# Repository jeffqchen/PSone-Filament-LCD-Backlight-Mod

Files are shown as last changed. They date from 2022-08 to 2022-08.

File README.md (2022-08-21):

# PSone Filament LCD Backlight Mod

The official PSone LCD screen has a fragile backlight system. The inverter and the CCFL tube could kick the bucket on itself. Sometimes you can't even figure out what went wrong with the backlight system. It's also nearly impossible to find the exact replacement parts at a reasonable price, even if you managed to figure it out.

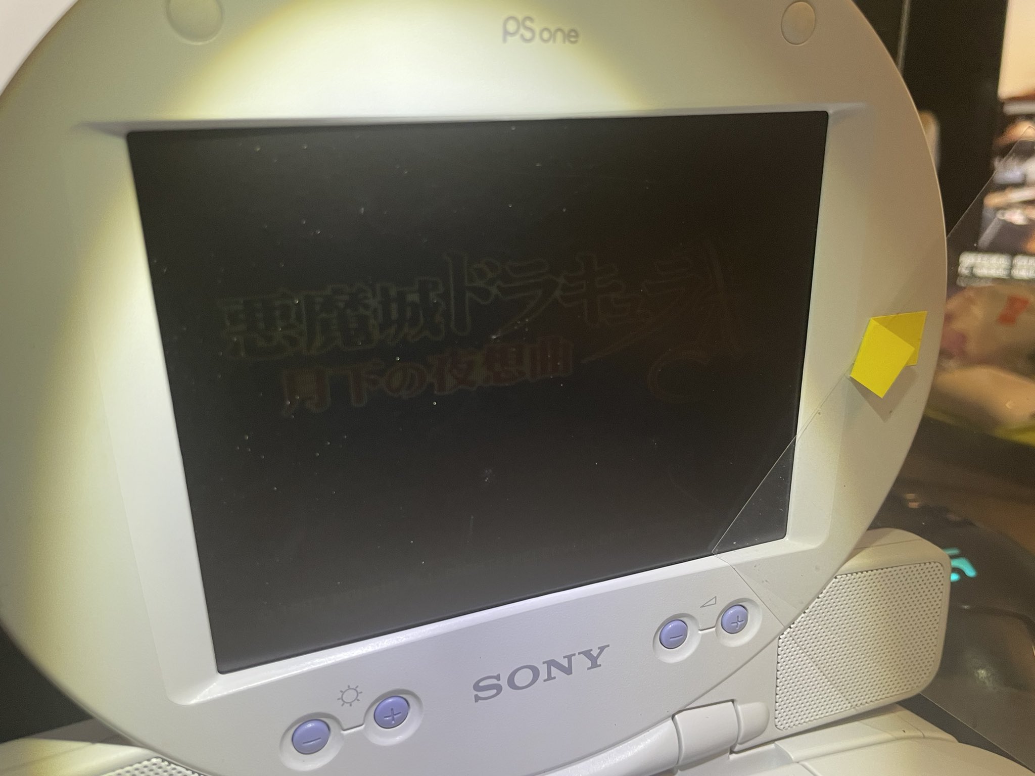
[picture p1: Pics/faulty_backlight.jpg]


Previously, there were multiple attempts of similar mods. But they all used singular LEDs, and resulted in uneven backlight that's difficult to look at. This new type of flexible filament LED provides the uniformity as good as the CCFL tube, and is very easy to manipulate. More importantly, they are very affordable.

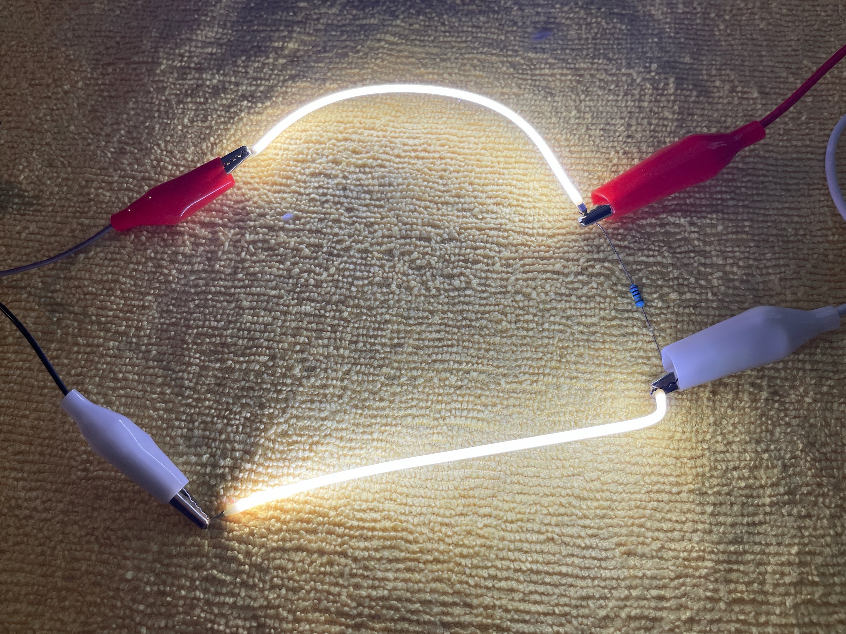
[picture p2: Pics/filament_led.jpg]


So here is my solution, just in case you are facing the dilemma (however, by all means, please try to diagnose and fix the original system if possible).

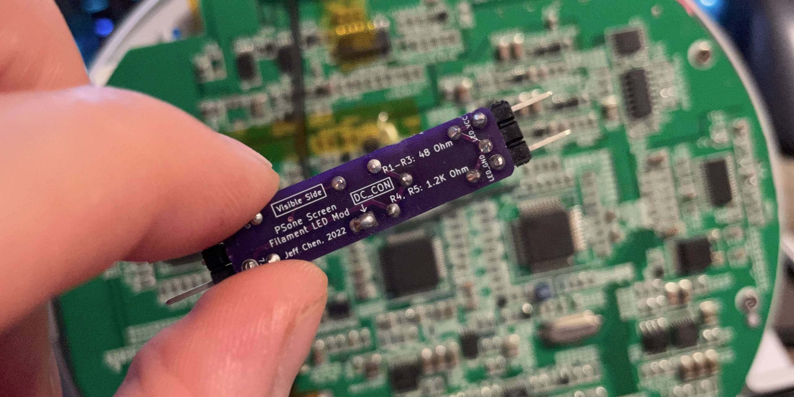
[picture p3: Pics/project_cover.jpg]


This design takes the 7.5V from the power input, runs it through an NPN amplifier, to feed power through two 3V flexible filament LED strips and some current-limiting resistors, controlled by the 5V_CON signal from the console.

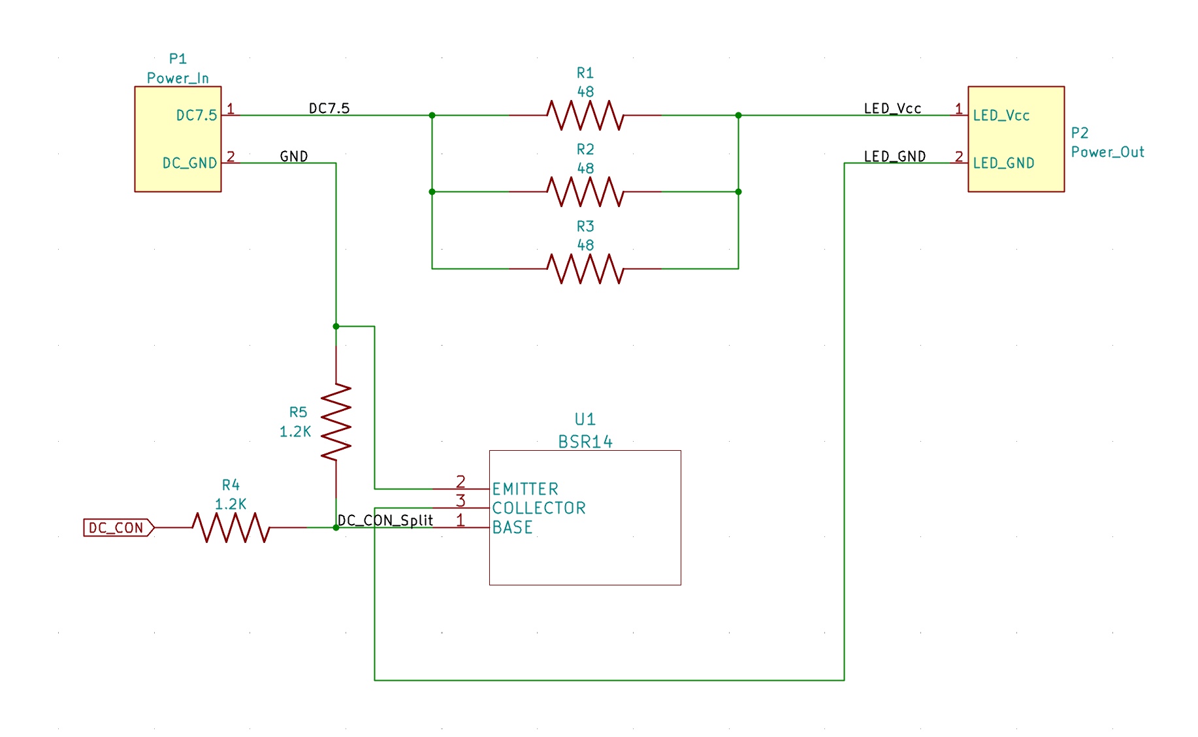
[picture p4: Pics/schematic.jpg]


Please note these values were fine tuned and do not match the perfect calculations. Somehow these filament LED strips do not drop the claimed voltage and I had to reduce the value of the current-limiting resistors to make them emit enough light. I did let the system run for an extended period of time to make sure it would last. The operation temperature was still much lower than the original design.

----------
## Parts

- [PCB](https://oshpark.com/shared_projects/M3fZRLg5)

- BSR14 NPN Amplifier / SOT23-3 - [Link](https://github.com/jeffqchen/JeffParts/blob/main/Components/BSR14%20NPN%20Amplifier/info.md)

- [2x] Flexible Filament LED Strips, 130mm, DC 3V, Cold White 6500K - [Link](https://github.com/jeffqchen/JeffParts/blob/main/Parts/Flexible%20Filament%20LED/info.md)

- 2.54mm-Pitched Pin Header, Right Angle  - [Link](https://github.com/jeffqchen/JeffParts/blob/main/Connectors/Pin%20Header/2.54mm%20Pitch/Male%20Right-Angle/info.md)

**All resistors are 1/4W through hole resistors.**

- R1-3: 48 Ohm
- R4, R5: 1.2K Ohm

----------
## PCB Assembly

Nothing is special about populating the parts.

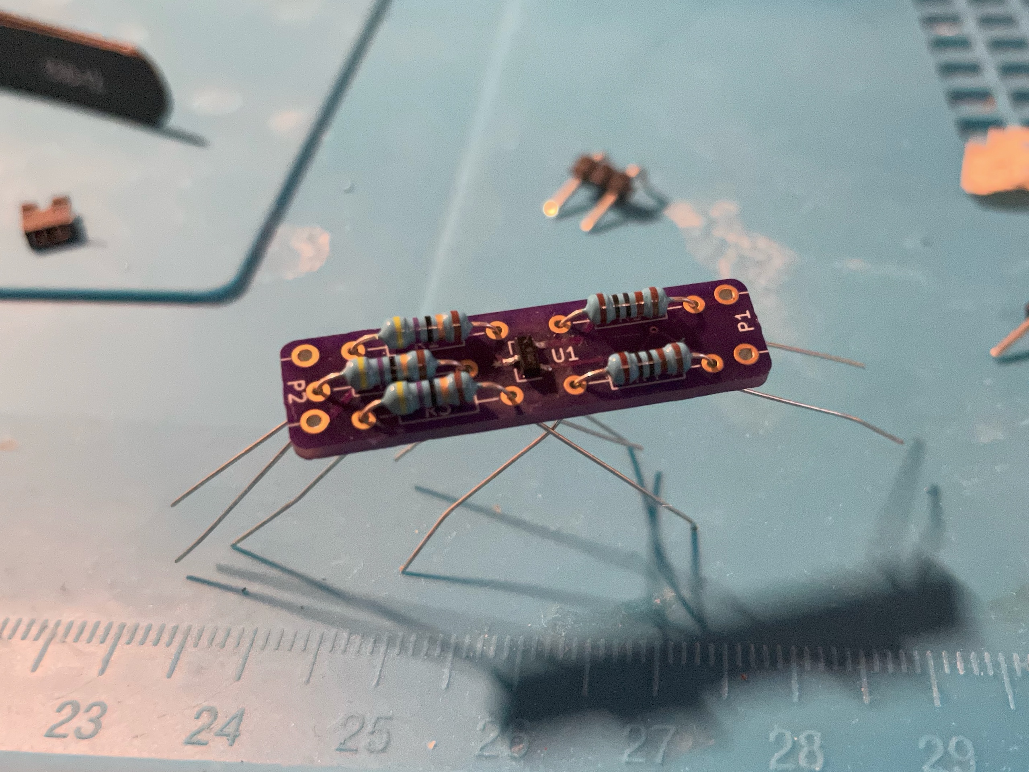
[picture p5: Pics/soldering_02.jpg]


Make sure the right-angled pin headers are on the invisible side of the PCB.

Only two pins are necessary on each side of the PCB.

Note you need 3 pins in a row but have to skip the middle one. You might want to cut off the middle one before hand.

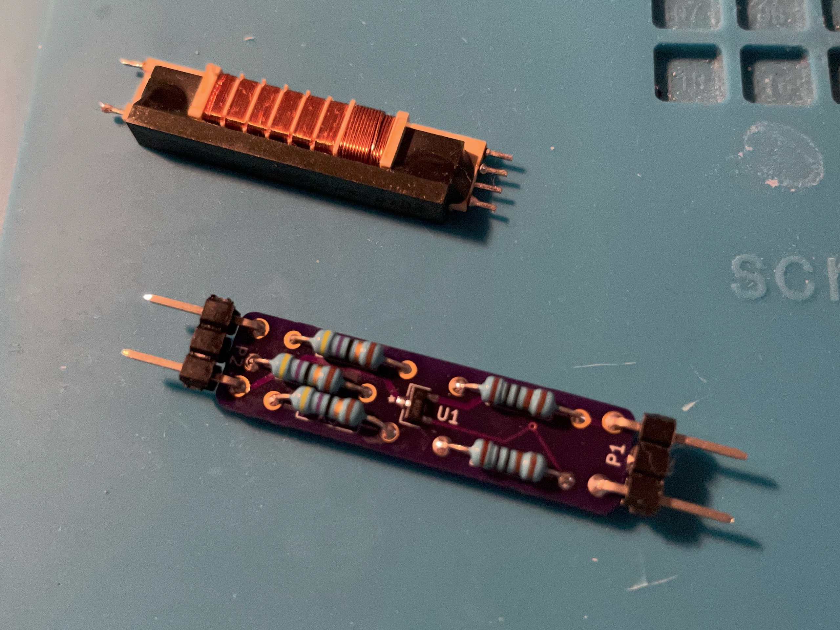
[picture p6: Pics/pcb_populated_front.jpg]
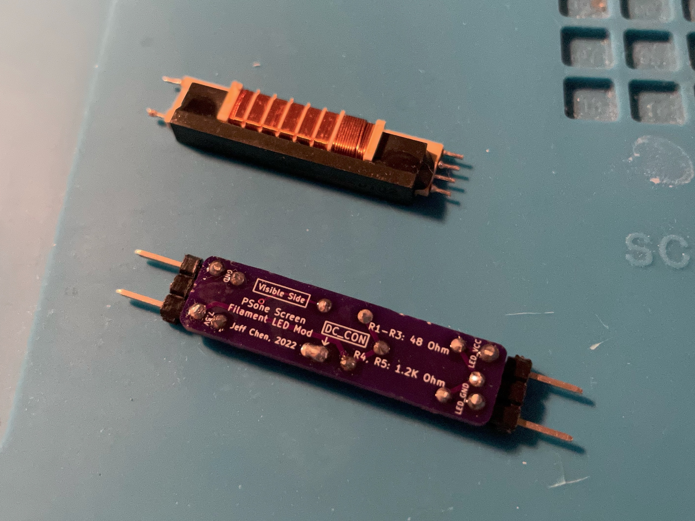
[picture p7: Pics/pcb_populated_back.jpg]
 

Cut and remove the black spacer after the pins are soldered in place.

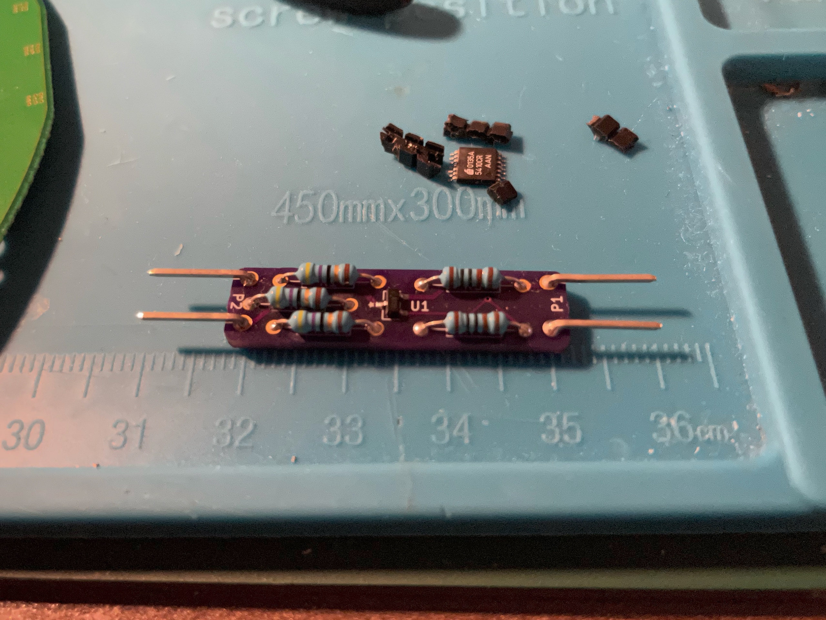
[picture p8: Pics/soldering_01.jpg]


Trim the legs somewhat so they don't reach too far into the main PCB when installed.

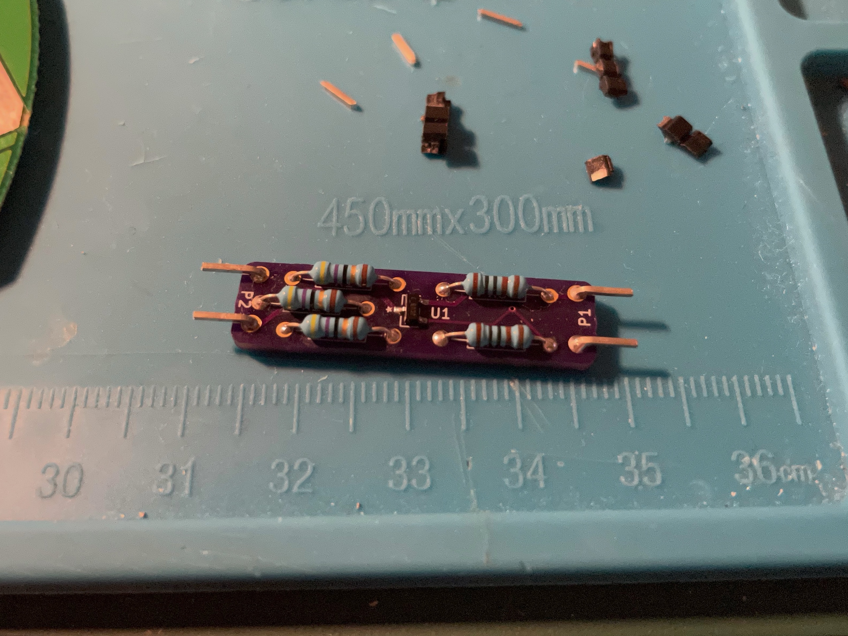
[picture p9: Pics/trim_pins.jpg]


----------
## PSone Screen Motherboard Modding

- Remove component C114, C116, C117, T1
- Cut the thick trace next to CN3 marked with a cross.

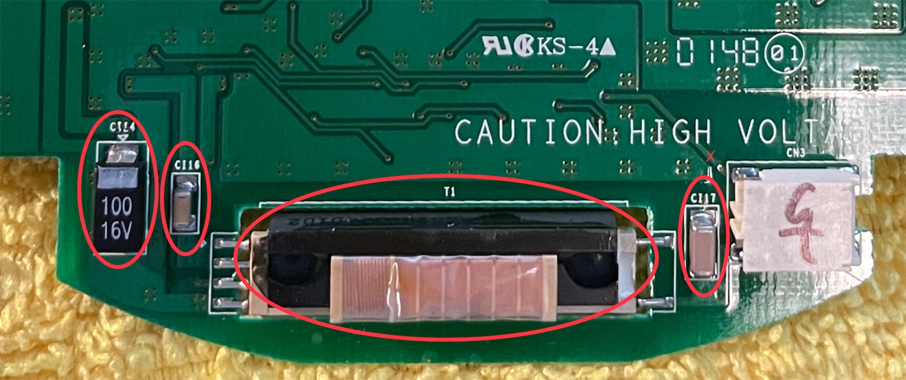
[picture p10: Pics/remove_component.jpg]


----------
## Installing Mod PCB

Solder the pin headers to the inside of the motherboard as shown in the photo.

Solder two jumper wires as shown in the photo.

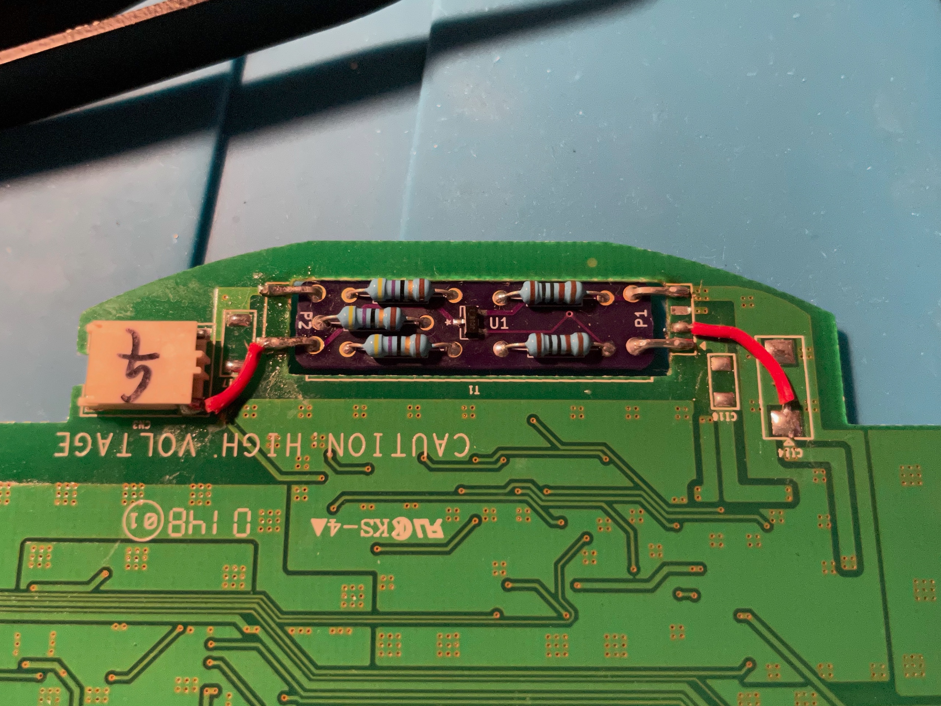
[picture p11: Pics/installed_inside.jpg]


Solder a wire to test point DC_CON on the motherboard, and solder the other end to the DC_CON on the mod board, as indicated in the photo.

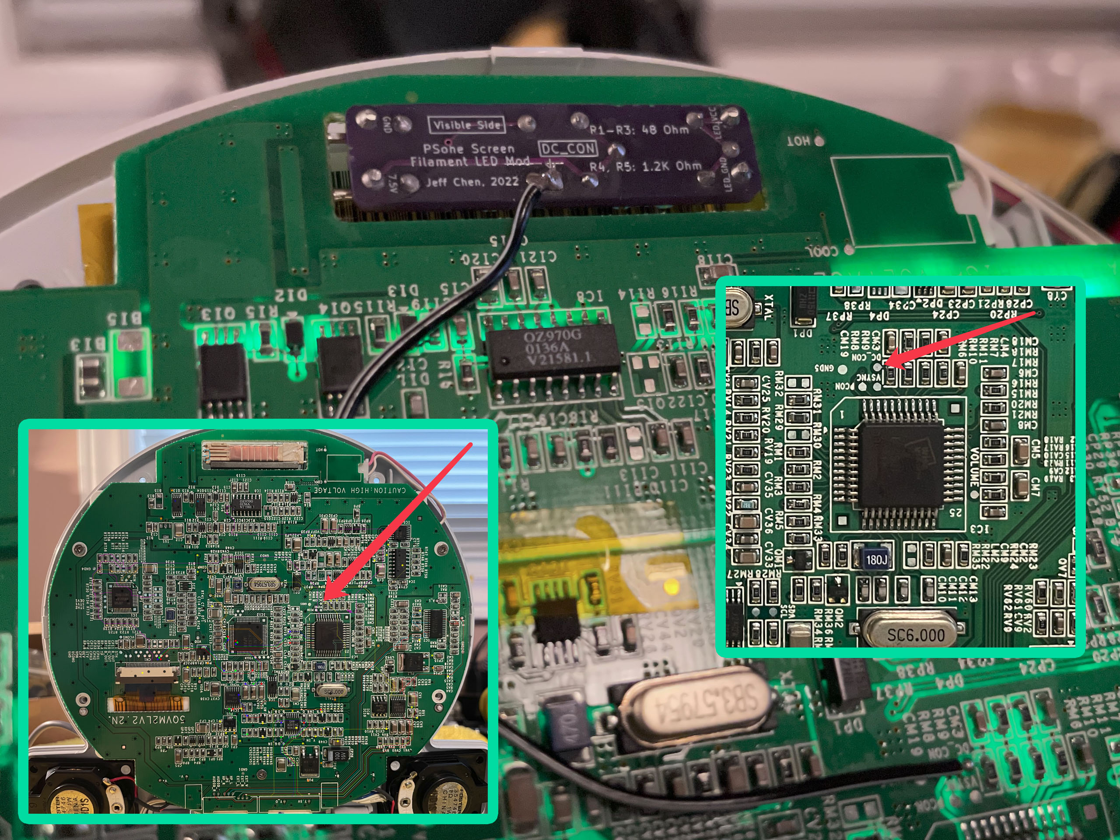
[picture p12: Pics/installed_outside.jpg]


----------
## Modding Backlight Assembly

Solder TWO flexible filament LEDs in series with a 60mm-long wire connecting them in the middle.

The polarity of the LED strips is important and requires attention.

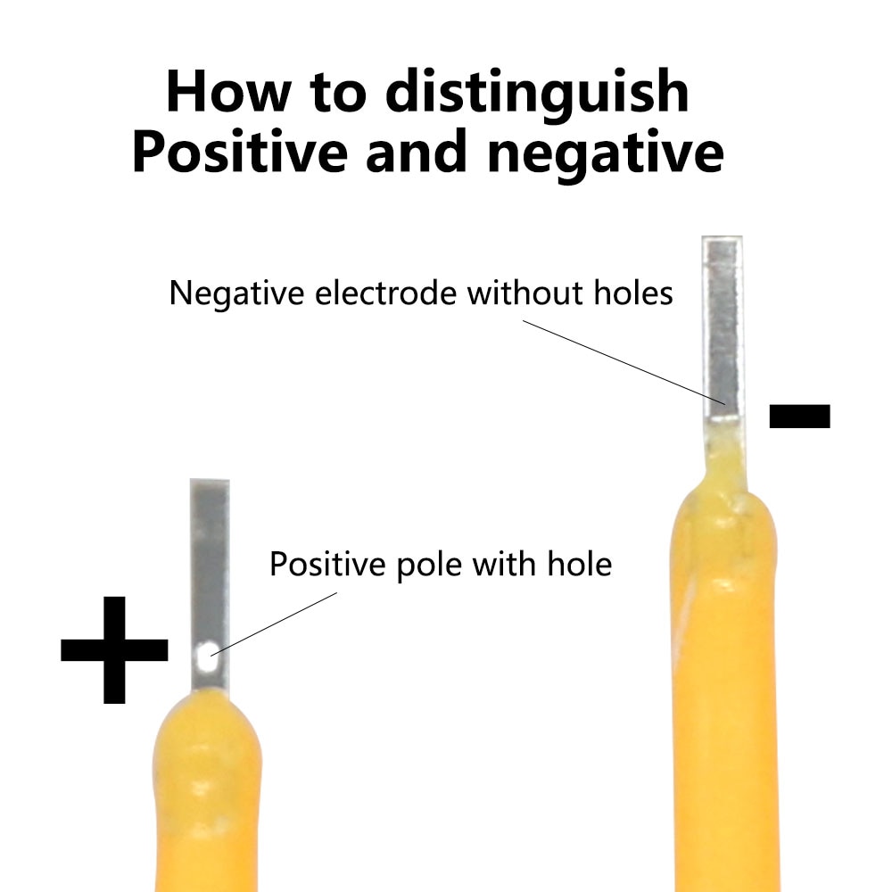
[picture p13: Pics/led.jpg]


Disassemble the screen, and open up the backlight box assembly.

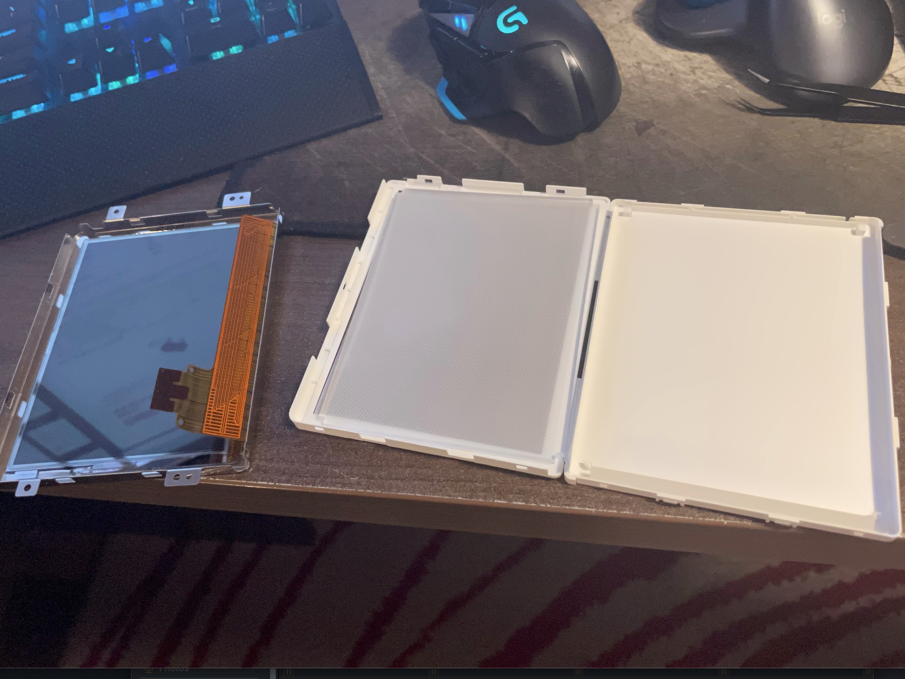
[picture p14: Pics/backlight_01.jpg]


**VERY CAREFULLY** remove the CCFL tube.

-----------
### To Reuse The Original CCFL Plug

Desolder the plug from the tube.

*Store the CCFL in a rigid environment so it doesn't have the chance to break.*

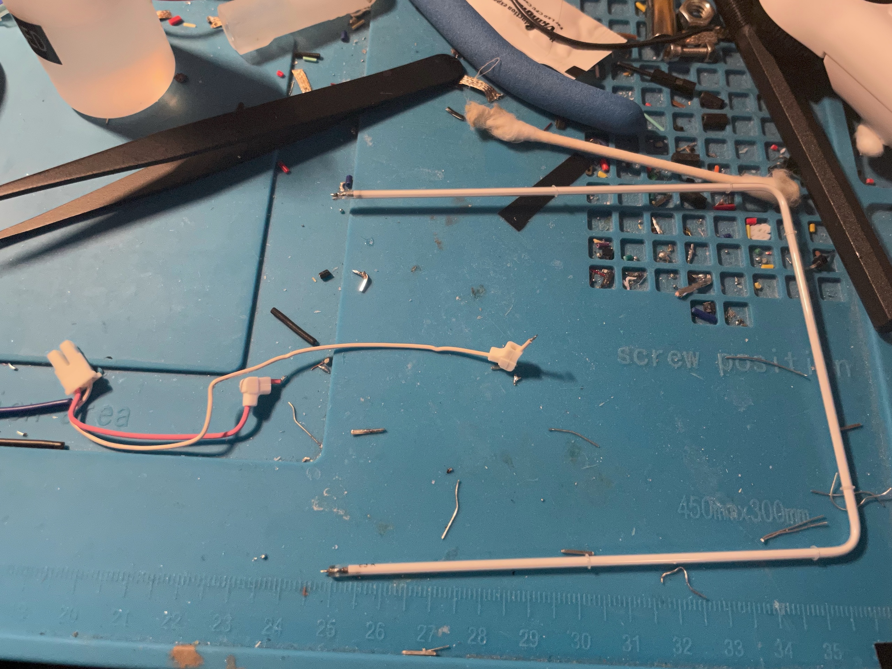
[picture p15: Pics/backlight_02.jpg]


Solder the red wire to the positive end of the LED filament in series, and the white wire to the negative end of the other LED.

*If you decided not to use the original CCFL plug, solder the positive end to the upper pin on the mod board with a piece of wire, and the negative end to the lower one with another.*

-----------

Fit the new LED assembly back into the backlight box like the original, then reassemble the entire LCD screen assembly.

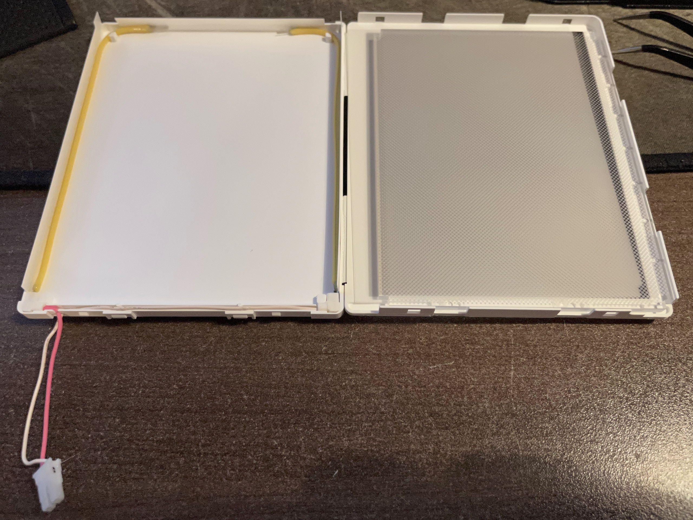
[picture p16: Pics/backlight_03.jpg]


----------
## Reassembly

Reseat the screen into the shell.

Reseat the motherboard onto the back of the screen assembly, then plug in the screen ribbon cable and lock the tab. Plug back in the screen backlight header.

To safely test the machine, secure the motherboard with at least two screws so the screen doesn't fall apart and cause damage.

----------
## Result

The backlight should now work. The backlight will not turn on until the PSone is powered on, exactly like how the screen is supposed to work.

The uniformity of the new backlight should be great - exactly like the original CCFL.

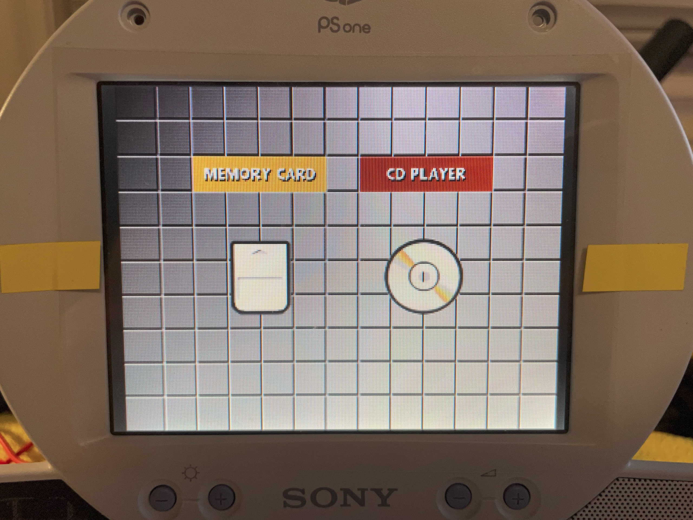
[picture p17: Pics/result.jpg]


The color temperature of these filament LEDs is different from the original, as compared below. Personally I think the original CCFL was too blue and the LEDs look more natural.

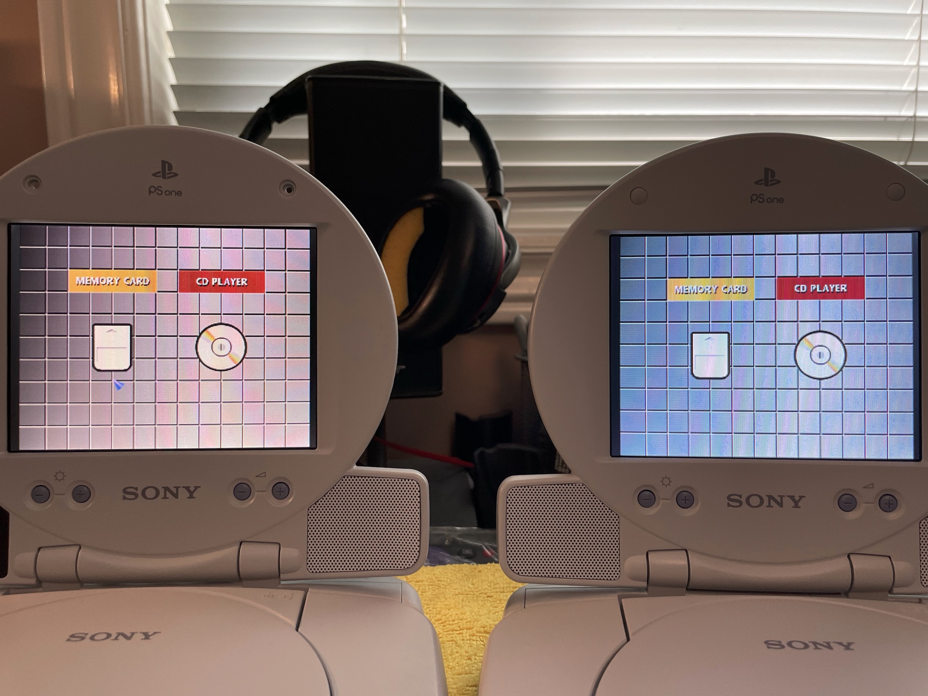
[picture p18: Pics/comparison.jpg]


----------
## Special Thanks

### [Zaxour](https://twitter.com/zaxour)
- For his original circuit design for the PSone LED mod - [Link](https://github.com/zaxour/PsOne_LEDBoard)

----------
Shield: [][cc-by-sa]

This work is licensed under a
[Creative Commons Attribution-ShareAlike 4.0 International License][cc-by-sa].

[][cc-by-sa]

[cc-by-sa]: http://creativecommons.org/licenses/by-sa/4.0/
[cc-by-sa-image]: https://licensebuttons.net/l/by-sa/4.0/88x31.png
[cc-by-sa-shield]: https://img.shields.io/badge/License-CC%20BY--SA%204.0-lightgrey.svg

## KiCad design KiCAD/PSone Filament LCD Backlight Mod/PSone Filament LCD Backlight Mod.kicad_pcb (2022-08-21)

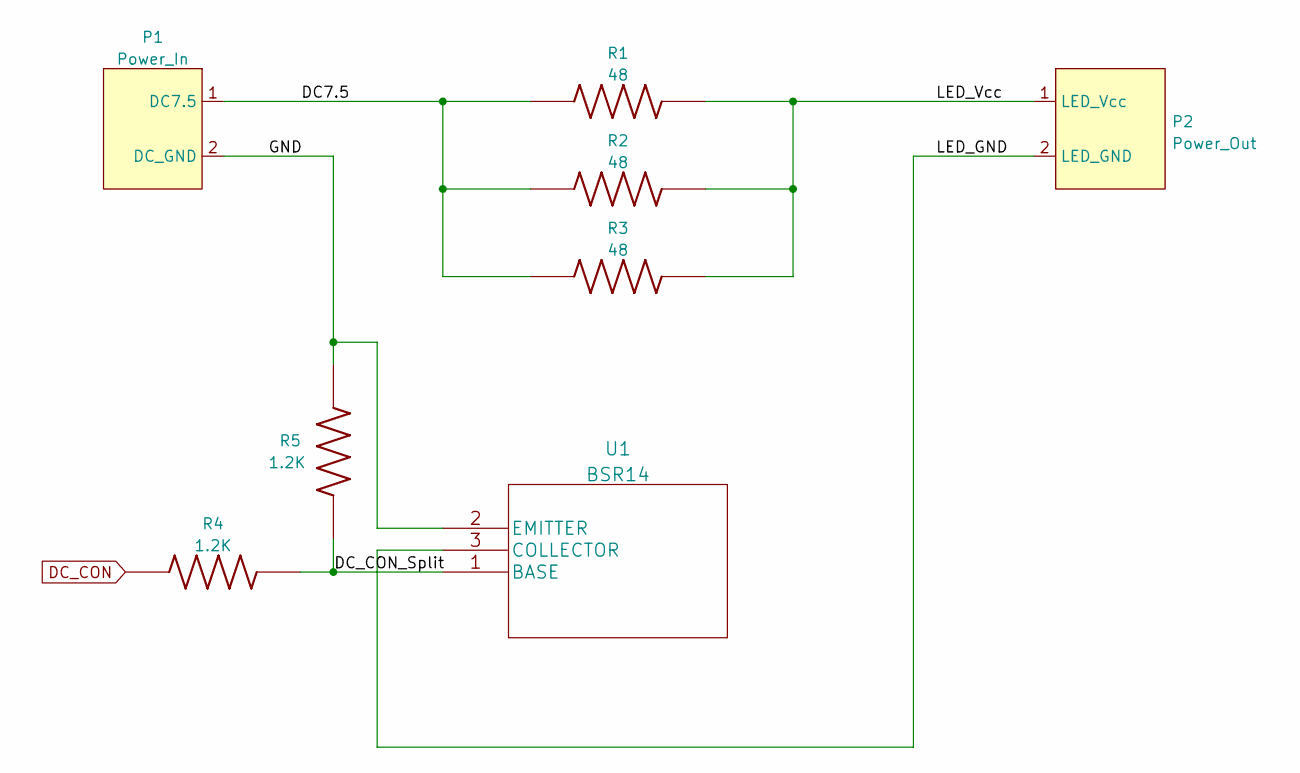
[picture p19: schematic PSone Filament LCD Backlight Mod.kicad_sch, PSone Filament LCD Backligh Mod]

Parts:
P1: Power_In; DC75IN
P2: Power_Out; LED_PWR
R1, R2, R3: 48; THT_Resistor
R4, R5: 1.2K; THT_Resistor
U1: BSR14

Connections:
/DC7.5: P1.1 (DC7.5), R1.1, R2.1, R3.1
/DC_CON_Split: R4.2, R5.1, U1.1 (BASE)
/GND: P1.2 (DC_GND), R5.2, U1.2 (EMITTER)
/LED_GND: P2.2 (LED_GND), U1.3 (COLLECTOR)
/LED_Vcc: P2.1 (LED_Vcc), R1.2, R2.2, R3.2
DC_CON: R4.1

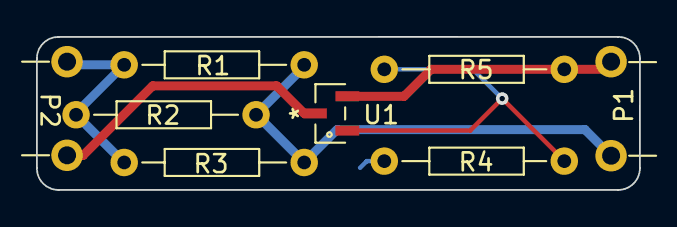
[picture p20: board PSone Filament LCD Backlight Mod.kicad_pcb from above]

Board: 2 copper layers, 33.5 x 8.5 mm, 8 parts (0 on the bottom side), 5 nets.

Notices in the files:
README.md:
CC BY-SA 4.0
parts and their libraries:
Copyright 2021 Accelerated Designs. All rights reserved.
